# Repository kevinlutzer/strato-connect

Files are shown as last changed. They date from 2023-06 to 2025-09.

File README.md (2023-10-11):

# Strato Connect

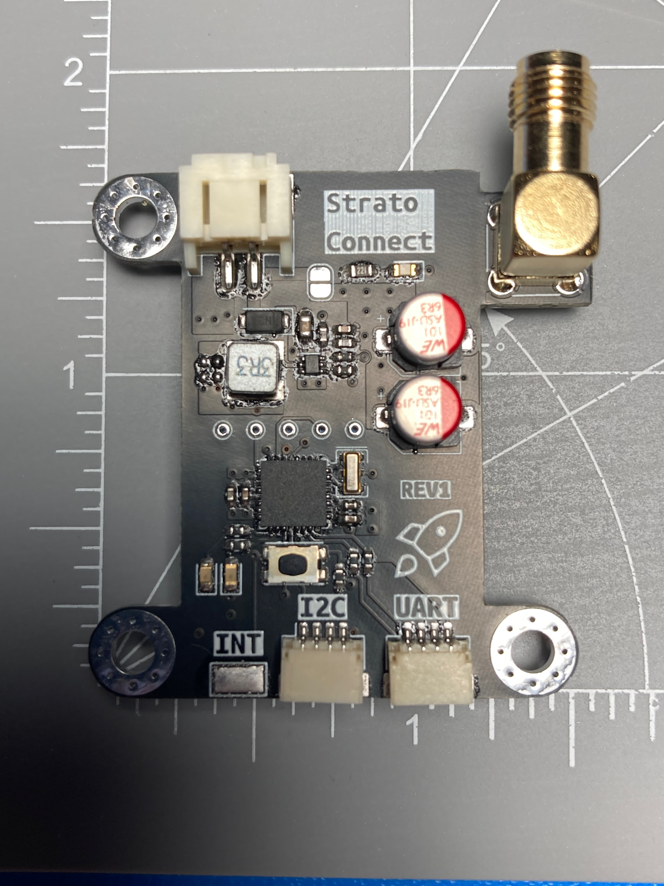
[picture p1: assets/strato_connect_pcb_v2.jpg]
Strato Connect V2 PCB Strato Connect


Strato Connect is an RF module used to send AX.25 formatted data with (G)FSK modulation over I2C. Connect a host MCU or computer to this module, and you can communicate with any AX.25 supported receiver up to 100 kilometers line of sight. 

# Rev 2.0 PCB Todo
1. The current boost regulator doesn't really work. We are getting voltage drops when there are current spikes. 
1. IRQ was not connected.
1. RX/TX labels are wrong for the uart port. 
1. Switch the JST connectors to be the 1.0mm pitch connector type used for QT/QWICC
1. Refactor the code to take an interface in for the I2C Controller instead of passing a function pointer

# Code
To compile and run tests use: `g++ test/test.cpp ax25/ax25.* test/ax25_test.h -lgtest -std=c++17 && ./a.out`
To compile code for arduino use: `arduino-cli compile -b MiniCore:avr:328 --library=./rf4463,./ax25 --output-dir=bin`

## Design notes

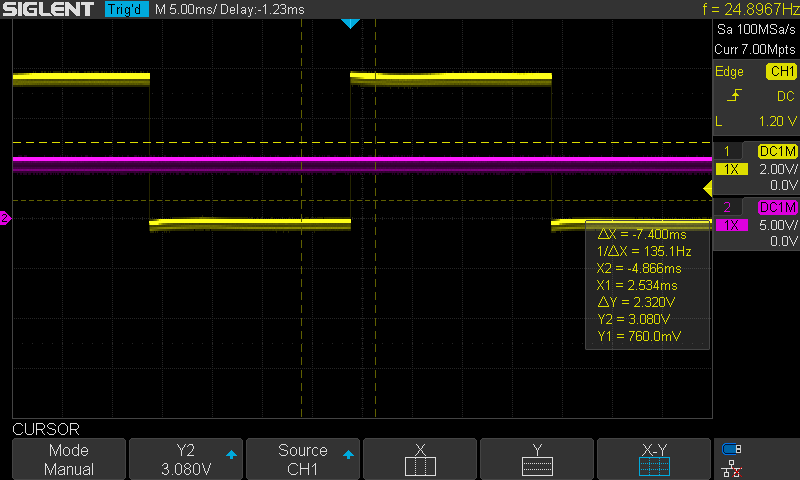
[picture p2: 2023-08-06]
documentation/SDS00004.png

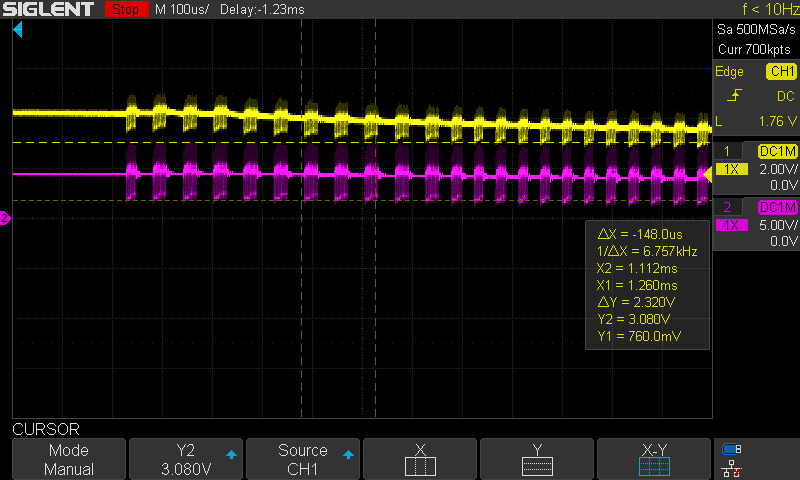
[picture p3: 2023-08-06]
documentation/SDS00003.png

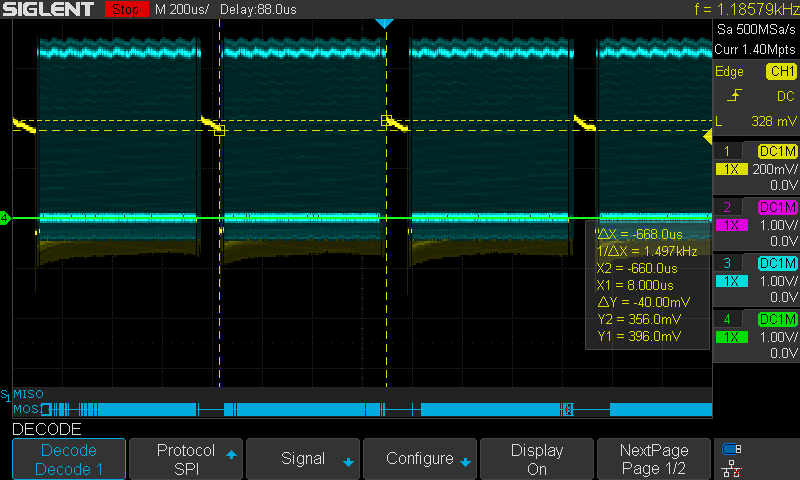
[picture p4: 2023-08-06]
documentation/SDS00001.png

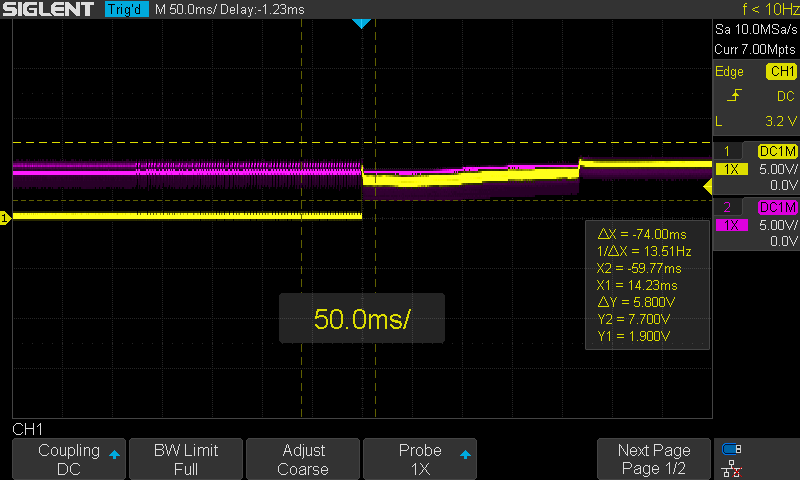
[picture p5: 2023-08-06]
documentation/SDS00005.png

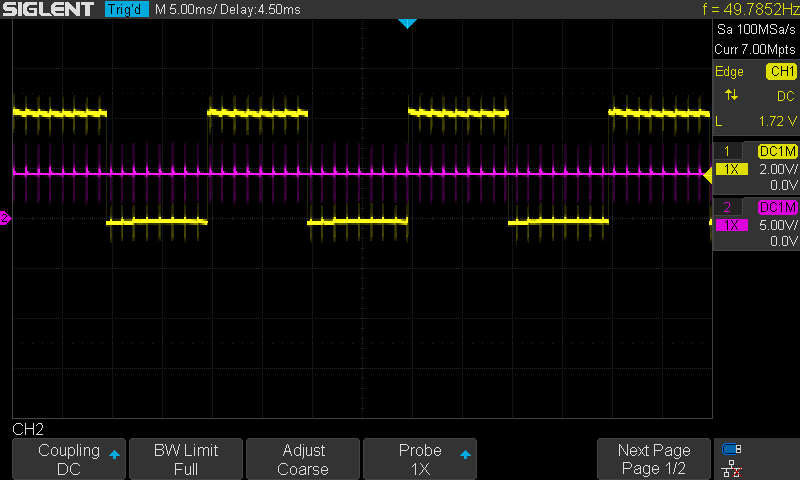
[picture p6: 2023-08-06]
documentation/SDS00002.png

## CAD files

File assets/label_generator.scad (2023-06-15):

/*
    Creates labels for the diode ring modulator pcb

    Author: Kevin Lutzer
    Date: June 13 2023
*/

// generates a rounded box with some text in the center
module generateLabel(width, height, radius, label, ts) {
    $fn=40;

    difference() {
        translate([- width / 2, - height / 2]) {
            minkowski() {
              square([width, height]);
              circle(r=radius);
            }
        }

        text(label, font="Liberation SansL:style=Bold", valign="center", halign="center", size=ts);        
    }

            
}

module generatePinHeader(width, height, radius, ts, labels, pin_pitch=2.54) {
    $fn=40;

    difference() {
        translate([- width / 2, - height / 2]) {
            minkowski() {
              square([width, height]);
              circle(r=radius);
            }
        }
        
        labels_len = len(labels);
        for (i = [0:1:len(labels)]) {
            label = labels[len(labels) - 1 - i];
            translate([-width/2, - (pin_pitch * labels_len)/2 + pin_pitch*i + pin_pitch / 2 ])
                text(label, font="Liberation Sans:style=Bold", valign="center", halign="left", size=ts);
        }
                        
    }            
}


//generatePinHeader(3.75, 4, 0.25, 1.2, ["TX", "GND", "RX"], 1.25); // UART header
//generatePinHeader(3.75, 6, 0.25, 1.2, ["GND", "VIN", "SDA", "SCL", "INT"], 1.25); // UART header
//generatePinHeader(3.75, 4, 0.25, 1.2, ["GND", "VIN"], 2.54); // Power header
//generateLabel(11.5, 1.75, 0.25, "StratoConnect", 1.2);
//generateLabel(5, 1.75, 0.25, "Rev 1", 1.2);
//generateLabel(6, 1.75, 0.25, "VIN=5V", 1.2);
//generateLabel(17.5, 1.75, 0.25, "Bypass Level Shifting", 1.2);
//generateLabel(4.5, 1.75, 0.25, "TRIG", 1.2);
//generateLabel(3.75, 1.75, 0.25, "RST", 1.2);
generatePinHeader(2.5, 4, 0.25, 1.2, ["TX", "RX"], 2.54); // Power header

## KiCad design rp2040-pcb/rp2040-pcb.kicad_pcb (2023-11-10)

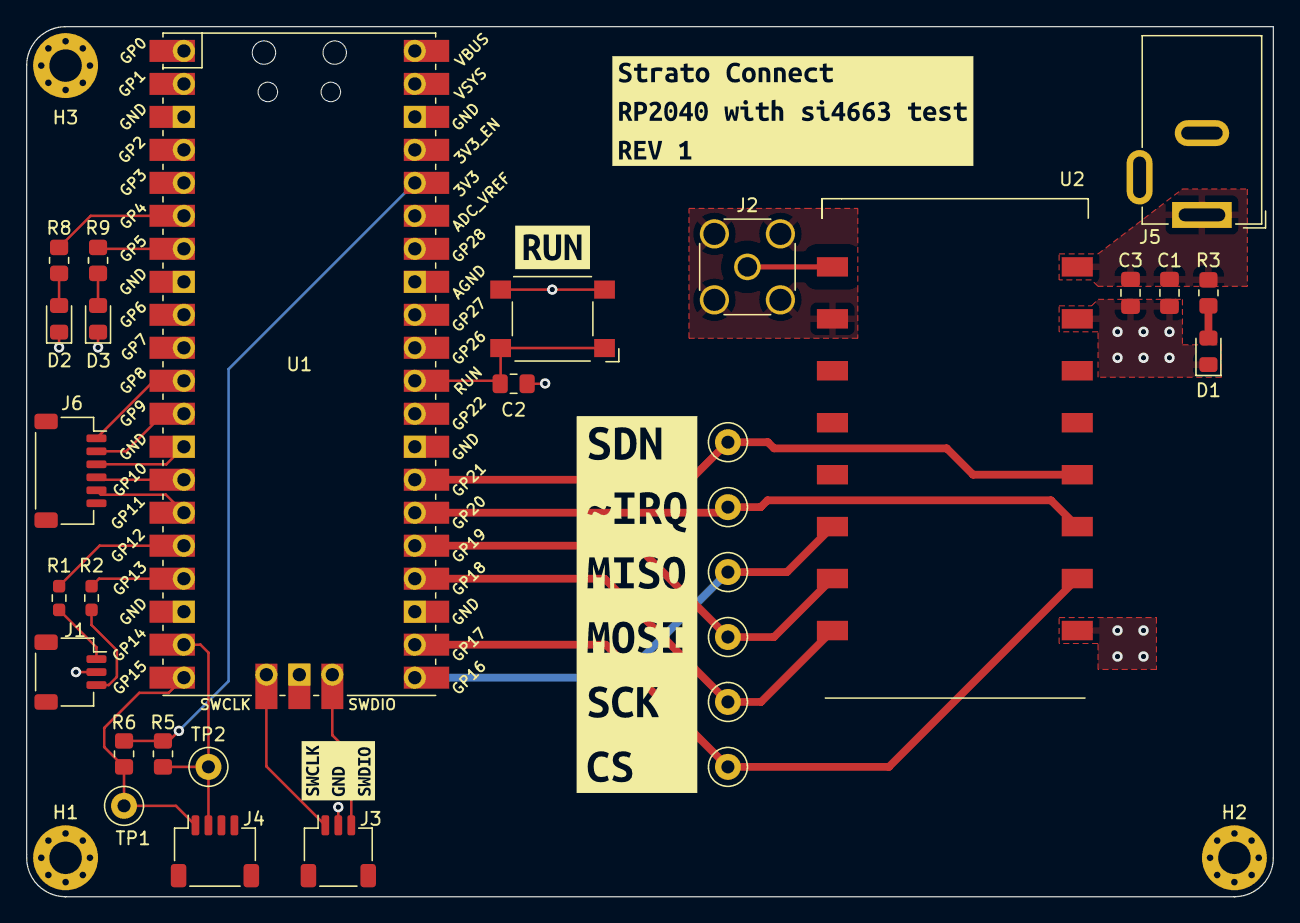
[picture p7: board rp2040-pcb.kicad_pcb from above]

Board: 2 copper layers, 96.0 x 67.0 mm, 37 parts (0 on the bottom side), 29 nets.

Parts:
C1, C2, C3: C; C_0805_2012Metric_Pad1.18x1.45mm_HandSolder
D1, D2, D3: LED; LED_0805_2012Metric_Pad1.15x1.40mm_HandSolder
H1, H2, H3: MountingHole_Pad; MountingHole_2.5mm_Pad_Via
J1, J3: Conn_01x03_Pin; JST_SH_SM03B-SRSS-TB_1x03-1MP_P1.00mm_Horizontal
J2: Conn_Coaxial; SMA_Wurth_60312002114503_Vertical
J4: Conn_01x04_Pin; JST_SH_SM04B-SRSS-TB_1x04-1MP_P1.00mm_Horizontal
J5: Barrel_Jack; BarrelJack_GCT_DCJ200-10-A_Horizontal
J6: Conn_01x06_Socket; JST_SH_SM06B-SRSS-TB_1x06-1MP_P1.00mm_Horizontal
R1, R2: 100; R_0603_1608Metric_Pad0.98x0.95mm_HandSolder
R3, R8, R9: 220; R_0805_2012Metric_Pad1.20x1.40mm_HandSolder
R5, R6: 2k2; R_0805_2012Metric_Pad1.20x1.40mm_HandSolder
SW1: SW_SPST; SW_SPST_Omron_B3FS-100xP
TP1, TP2, TP3, TP4, TP5, TP6, TP7, TP8: TestPoint; TestPoint_Loop_D1.80mm_Drill1.0mm_Beaded
U1: Pico; RPi_Pico_SMD_TH
U2: RF4463F30
kibuzzard-654DA23D: G***; kibuzzard-654DA23D
kibuzzard-654DA24D: G***; kibuzzard-654DA24D
kibuzzard-654DAC3C: G***; kibuzzard-654DAC3C
kibuzzard-654DC7E1: G***; kibuzzard-654DC7E1

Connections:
+3V3: R5.2, R6.2, U1.36 (3V3)
+VDC: C1.1, C3.1, J5.1, R3.1, U2.16 (VCC)
/RF_GND: J2.2 (Ext), U2.2 (ANT_GND)
GND: C1.2, C2.2, C3.2, D1.1 (K), D2.1 (K), D3.1 (K), H1.1, H2.1, H3.1, J1.2, J3.2, J4.4, J5.2, J6.3, SW1.2 (B), U1.3 (GND), U1.8 (GND), U1.13 (GND), U1.18 (GND), U1.23 (GND), U1.28 (GND), U1.33 (AGND), U1.38 (GND), U1.42 (GND), U2.9 (GND), U2.15 (GND)
I2C_SCL: J4.1, R6.1, TP1.1, U1.20 (GPIO15)
I2C_SDA: J4.2, R5.1, TP2.1, U1.19 (GPIO14)
LED1: R8.1, U1.6 (GPIO4)
LED2: R9.1, U1.7 (GPIO5)
unnamed: D1.2 (A), R3.2
unnamed: D2.2 (A), R8.2
unnamed: D3.2 (A), R9.2
unnamed: J1.1, R1.1
unnamed: J1.3, R2.1
unnamed: J2.1 (In), U2.1 (ANT)
RUN: C2.1, SW1.1 (A), U1.30 (RUN)
SDN: TP8.1, U1.27 (GPIO21), U2.12 (SDN)
SPI0_MISO: TP3.1, U1.21 (GPIO16), U2.6 (SDO)
SPI0_MOSI: TP4.1, U1.25 (GPIO19), U2.7 (SDI)
SPI0_SCK: TP5.1, U1.24 (GPIO18), U2.8 (SCLK)
SPI1_MISO: J6.1, U1.11 (GPIO8)
SPI1_MOSI: J6.5, U1.15 (GPIO11)
SPI1_SCK: J6.4, U1.14 (GPIO10)
SWCLK: J3.1, U1.41 (SWCLK)
SWDIO: J3.3, U1.43 (SWDIO)
UART_RX: R2.2, U1.17 (GPIO13)
UART_TX: R1.2, U1.16 (GPIO12)
~IRQ: TP7.1, U1.26 (GPIO20), U2.11 (~IRQ)
~SPI0_CS: TP6.1, U1.22 (GPIO17), U2.10 (~SEL)
~SPI1_CS: J6.2, U1.12 (GPIO9)

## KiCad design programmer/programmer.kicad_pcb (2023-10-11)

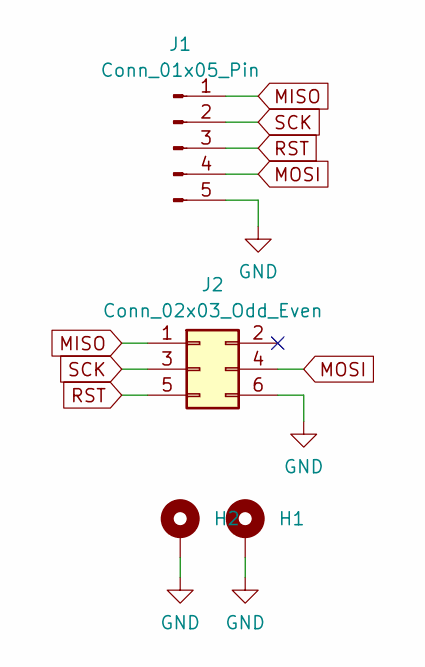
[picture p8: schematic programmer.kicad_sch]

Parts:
H1, H2: MountingHole_Pad; MountingHole_3mm_Pad_Via
J1: Conn_01x05_Pin; PinHeader_1x05_P2.54mm_Vertical
J2: Conn_02x03_Odd_Even; PinHeader_2x03_P2.54mm_Vertical

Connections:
GND: H1.1, H2.1, J1.5, J2.6
MISO: J1.1, J2.1
MOSI: J1.4, J2.4
RST: J1.3, J2.5
SCK: J1.2, J2.3

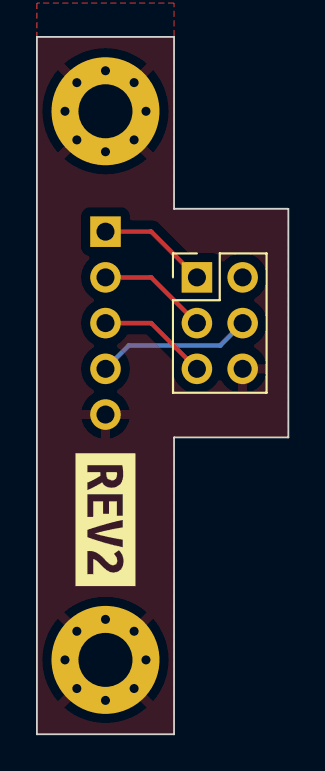
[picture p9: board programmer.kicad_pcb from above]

Board: 2 copper layers, 14.0 x 38.7 mm, 5 parts (1 on the bottom side), 5 nets.

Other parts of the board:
kibuzzard-64ED132C: G***; kibuzzard-64ED132C

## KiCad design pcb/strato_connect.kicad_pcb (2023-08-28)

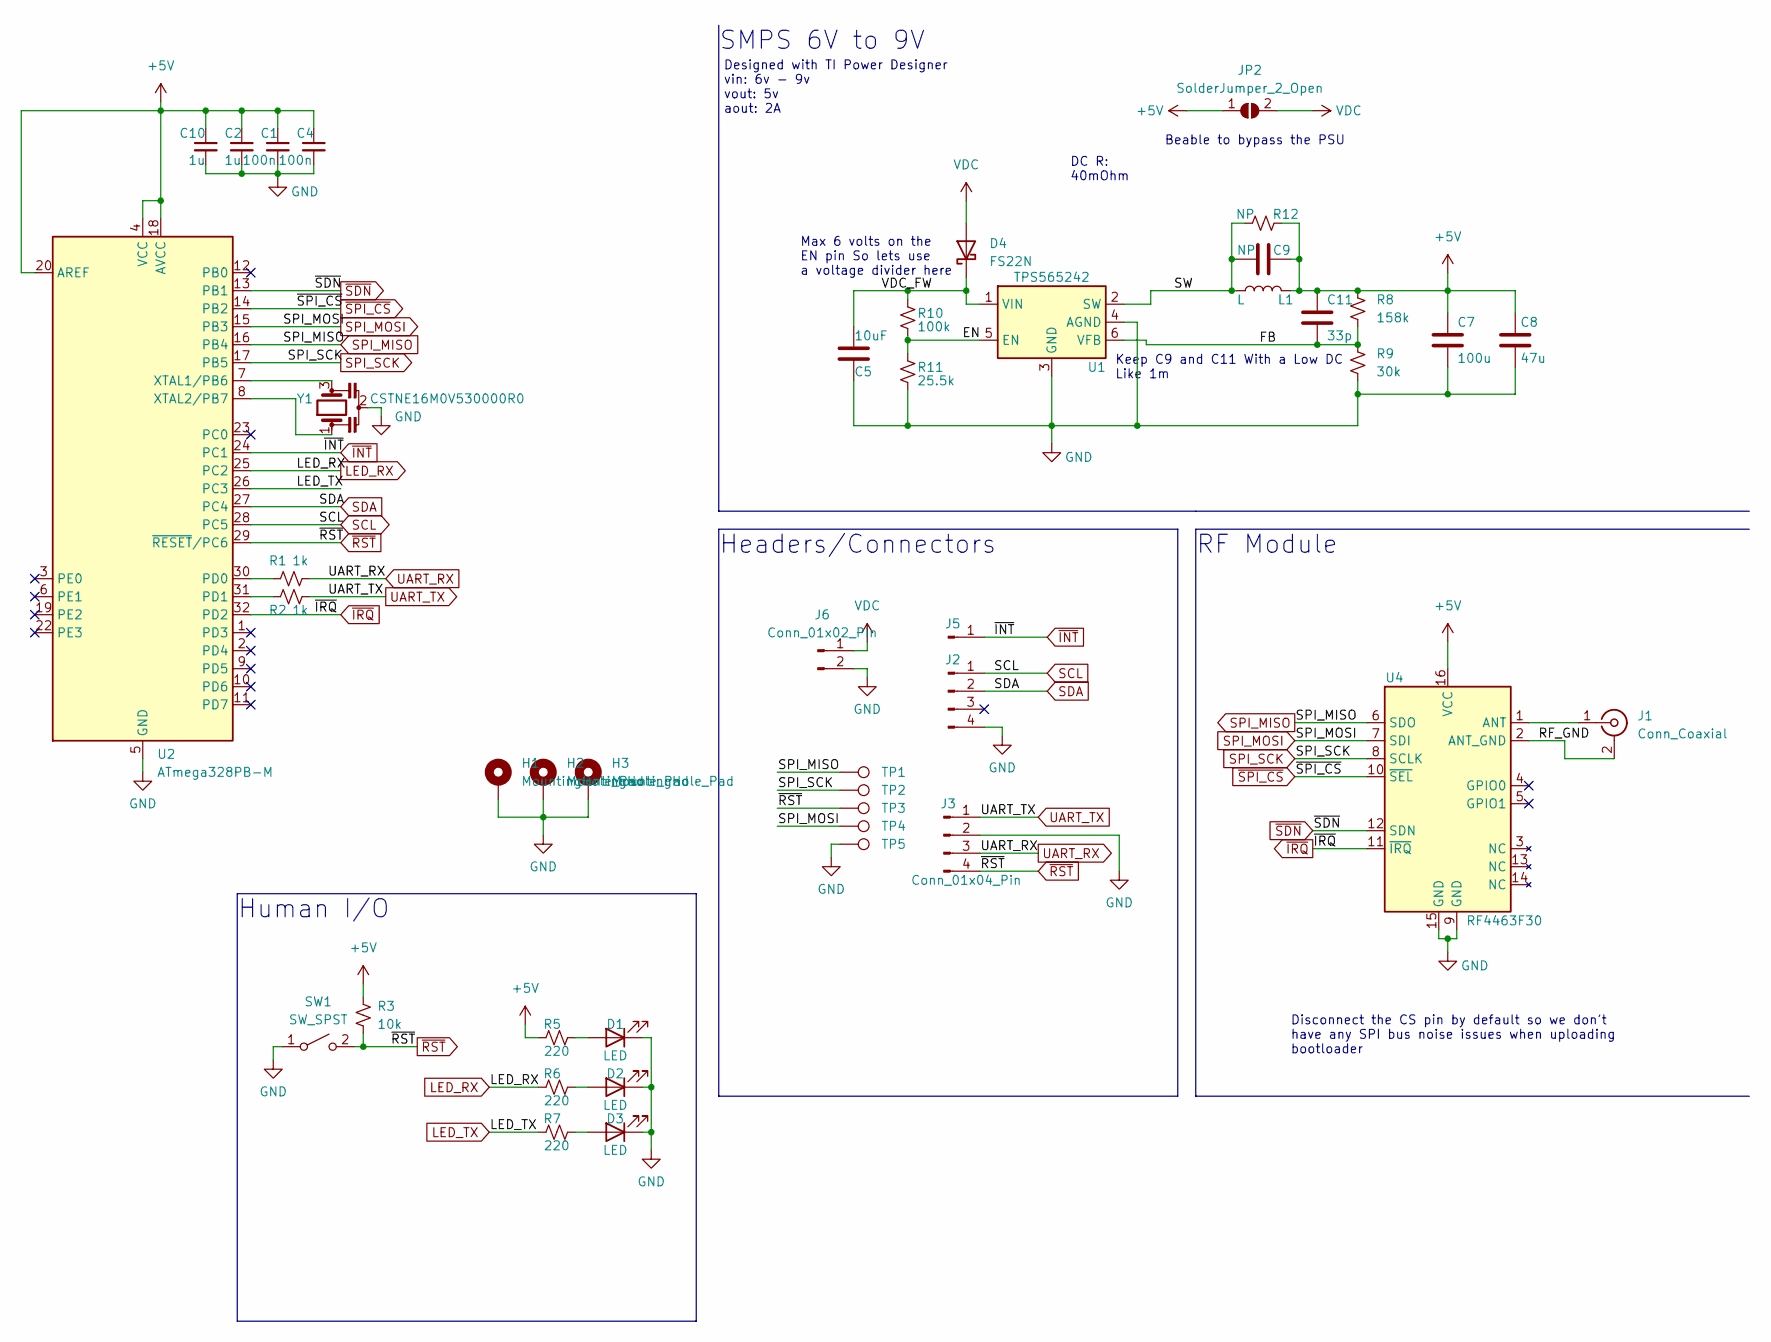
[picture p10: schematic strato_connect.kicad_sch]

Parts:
C1, C4: 100n; C_0402_1005Metric_Pad0.74x0.62mm_HandSolder
C2, C10: 1u; C_0402_1005Metric_Pad0.74x0.62mm_HandSolder
C5: 10uF; C_0603_1608Metric_Pad1.08x0.95mm_HandSolder
C7: 100u; CP_Elec_5x5.3
C8: 47u; CP_Elec_5x5.3
C9: NP; C_0402_1005Metric_Pad0.74x0.62mm_HandSolder
C11: 33p; C_0402_1005Metric_Pad0.74x0.62mm_HandSolder
D1, D2, D3: LED; LED_0603_1608Metric
D4: FS22N; D_SOD-123F
H1, H2, H3: MountingHole_Pad; MountingHole_3.2mm_M3_Pad_Via
J1: Conn_Coaxial; SMA_Wurth_60312002114503_Vertical
J2, J3: Conn_01x04_Pin; JST_SH_SM04B-SRSS-TB_1x04-1MP_P1.00mm_Horizontal
J5: Conn_01x01_Pin; TestPoint_Keystone_5019_Minature
J6: Conn_01x02_Pin; JST_PH_S2B-PH-SM4-TB_1x02-1MP_P2.00mm_Horizontal
JP2: SolderJumper_2_Open; SolderJumper-2_P1.3mm_Open_RoundedPad1.0x1.5mm
L1: L; L_Wurth_WE-LQSH-4025
R1, R2: 1k; R_0402_1005Metric_Pad0.72x0.64mm_HandSolder
R3: 10k; R_0402_1005Metric_Pad0.72x0.64mm_HandSolder
R5: 220; R_0603_1608Metric_Pad0.98x0.95mm_HandSolder
R6, R7: 220; R_0402_1005Metric_Pad0.72x0.64mm_HandSolder
R8: 158k; R_0402_1005Metric_Pad0.72x0.64mm_HandSolder
R9: 30k; R_0402_1005Metric_Pad0.72x0.64mm_HandSolder
R10: 100k; R_0402_1005Metric_Pad0.72x0.64mm_HandSolder
R11: 25.5k; R_0402_1005Metric_Pad0.72x0.64mm_HandSolder
R12: NP; R_0402_1005Metric_Pad0.72x0.64mm_HandSolder
SW1: SW_SPST; SW_Push_1P1T_NO_CK_KMR2
TP1, TP2, TP3, TP4, TP5: TestPoint; TestPoint_THTPad_D1.0mm_Drill0.5mm
U1: TPS565242; SOT-563
U2: ATmega328PB-M; QFN-32-1EP_5x5mm_P0.5mm_EP3.1x3.1mm
U4: RF4463F30
Y1: CSTNE16M0V530000R0; Resonator_SMD_Murata_CSTxExxV-3Pin_3.0x1.1mm

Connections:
+5V: C1.1, C2.1, C4.1, C7.1, C8.1, C9.1, C10.1, C11.1, JP2.1 (A), L1.2, R3.1, R5.1, R8.1, R12.2, U2.4 (VCC), U2.18 (AVCC), U2.20 (AREF), U4.16 (VCC)
/EN: R10.2, R11.1, U1.5 (EN)
/FB: C11.2, R8.2, R9.1, U1.6 (VFB)
/RF_GND: J1.2 (Ext), U4.2 (ANT_GND)
/SW: C9.2, L1.1, R12.1, U1.2 (SW)
/VDC_FW: C5.1, D4.1 (K), R10.1, U1.1 (VIN)
GND: C1.2, C2.2, C4.2, C5.2, C7.2, C8.2, C10.2, D1.1 (K), D2.1 (K), D3.1 (K), H1.1, H2.1, H3.1, J2.4, J3.2, J6.2, R9.2, R11.2, SW1.1 (A), TP5.1, U1.3 (GND), U1.4 (AGND), U2.5 (GND), U2.21 (GND), U2.33 (GND), U4.9 (GND), U4.15 (GND), Y1.2
LED_RX: R6.1, U2.25 (PC2)
LED_TX: R7.1, U2.26 (PC3)
unnamed: D1.2 (A), R5.2
unnamed: D2.2 (A), R6.2
unnamed: D3.2 (A), R7.2
unnamed: J1.1 (In), U4.1 (ANT)
unnamed: R1.1, U2.30 (PD0)
unnamed: R2.1, U2.31 (PD1)
unnamed: U2.7 (XTAL1/PB6), Y1.3
unnamed: U2.8 (XTAL2/PB7), Y1.1
SCL: J2.1, U2.28 (PC5)
SDA: J2.2, U2.27 (PC4)
SPI_MISO: TP1.1, U2.16 (PB4), U4.6 (SDO)
SPI_MOSI: TP4.1, U2.15 (PB3), U4.7 (SDI)
SPI_SCK: TP2.1, U2.17 (PB5), U4.8 (SCLK)
UART_RX: J3.3, R1.2
UART_TX: J3.1, R2.2
VDC: D4.2 (A), J6.1, JP2.2 (B)
~INT: J5.1, U2.24 (PC1)
~IRQ: U2.32 (PD2), U4.11 (~IRQ)
~RST: J3.4, R3.2, SW1.2 (B), TP3.1, U2.29 (~RESET/PC6)
~SDN: U2.13 (PB1), U4.12 (SDN)
~SPI_CS: U2.14 (PB2), U4.10 (~SEL)

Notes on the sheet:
Headers/Connectors
Human I/O
DC R: 40mOhm
SMPS 6V to 9V
Max 6 volts on the EN pin So lets use a voltage divider here
Keep C9 and C11 With a Low DC Like 1m
Designed with TI Power Designer vin: 6v - 9v vout: 5v aout: 2A
RF Module
Disconnect the CS pin by default so we don't have any SPI bus noise issues when uploading bootloader
Beable to bypass the PSU

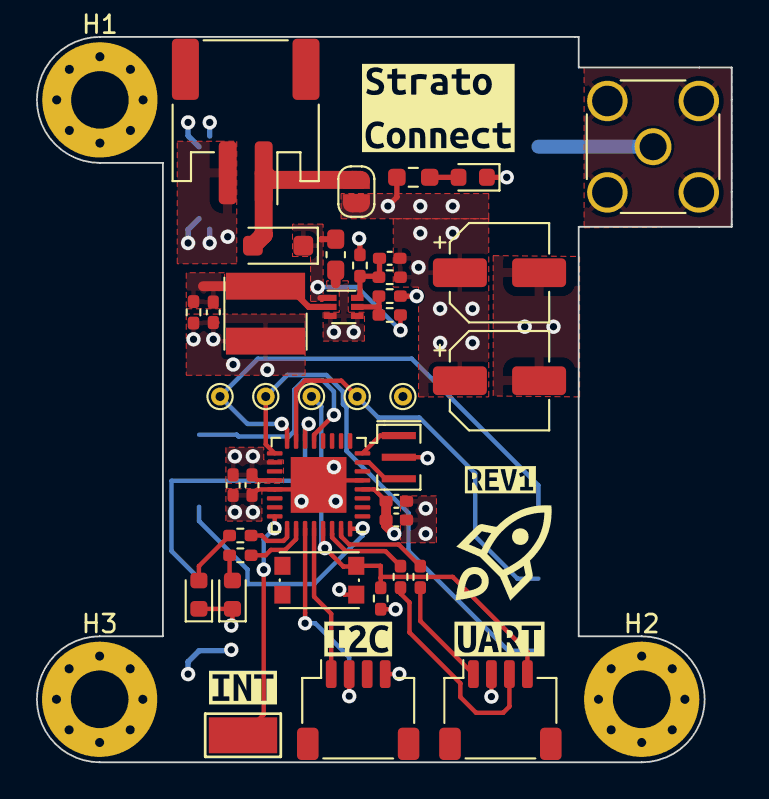
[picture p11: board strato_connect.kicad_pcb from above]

Board: 4 copper layers, 38.6 x 40.3 mm, 49 parts (1 on the bottom side), 30 nets.

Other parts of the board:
kibuzzard-64B1A87B: G***; kibuzzard-64B1A87B
kibuzzard-64B1A828: G***; kibuzzard-64B1A828
kibuzzard-64B1A895: G***; kibuzzard-64B1A895
kibuzzard-64B1B5E1: G***; kibuzzard-64B1B5E1
kibuzzard-64B1B6FD: G***; kibuzzard-64B1B6FD

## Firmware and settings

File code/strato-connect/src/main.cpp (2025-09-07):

#include "rf4463.hpp"
#include <SPI.h>
// #include "ax25.hpp"
// #include "i2ccontroller.hpp"
// #include <SPI.h>
// #include <Wire.h>
// #include <Adafruit_BME280.h>

#define IRQ 2
#define SDN 9
#define SEL 10
#define SCL 19

#define LED_RX 16
#define LED_TX 17
#define INT 15

// Raspberry Pi pico RP2040 pinout
#define SCK 10
#define MISO 11
#define MOSI 12
#define CS 13

SPIClass &spiClass = SPI1; 
RF4463 rf4463(IRQ, SDN, SEL);
unsigned char tx_buf[] = { "NEW HELLO WORLD!!!" };
unsigned char val;
unsigned char flag = 0;  //  flag of rx mode
unsigned char rx_len;
unsigned char rx_buf[20];

void setup() {
  Serial.begin(9600);

  pinMode(LED_RX, OUTPUT);
  pinMode(LED_TX, OUTPUT);
  pinMode(INT, OUTPUT);

  digitalWrite(LED_RX, HIGH);

  digitalWrite(INT, HIGH);

  if (!rf4463.init())
    Serial.println("Init fail!");
  else
    Serial.println("Init success!");

  if (!rf4463.setTxPower(127))
    Serial.println("Failed to set power to max!");
}

void loop() {
  digitalWrite(LED_TX, LOW);
  delay(1000);
  digitalWrite(LED_TX, HIGH);
  rf4463.txPacket(tx_buf, sizeof(tx_buf));
  delay(1000);
}

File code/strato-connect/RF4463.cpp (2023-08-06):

#include "RF4463.h"
#include <SPI.h>
// Generated with wireless development suite by silicon labs
#include "radio_config_Si4463.h"

// #define DEBUG_RF4463

// Configuration parameters from "radio_config_Si4463.h"
const uint8_t RF4463_CONFIGURATION_DATA[] = RADIO_CONFIGURATION_DATA_ARRAY;

RF4463::RF4463(uint8_t nIRQPin, uint8_t sdnPin,uint8_t nSELPin)
{
	_nIRQPin = nIRQPin;
	_sdnPin = sdnPin;
	_nSELPin = nSELPin;
}
void RF4463::spiInit()
{
	SPI.begin();
	//init slave select pin
	pinMode(_nSELPin, OUTPUT);
	digitalWrite(_nSELPin, HIGH);

	// depends on RF4463 spi timing
	SPI.setBitOrder(MSBFIRST);
  
	// too fast may cause error
	SPI.setClockDivider(SPI_CLOCK_DIV16);
	SPI.setDataMode(SPI_MODE0);
}
void RF4463::pinInit()
{
	pinMode(_sdnPin, OUTPUT);
	digitalWrite(_sdnPin, HIGH);
	pinMode(_nIRQPin, INPUT);
}
bool RF4463::init()
{
	pinInit();
	spiInit();

	uint8_t buf[20];

	// reset RF4463
	powerOnReset();


  	// check if RF4463 works
	if(!checkDevice())
	{
		return false;
	}


	// Set RF parameter,like frequency,data rate etc
	setConfig(RF4463_CONFIGURATION_DATA,sizeof(RF4463_CONFIGURATION_DATA));
	
	// set antenna switch,in RF4463 is GPIO2 and GPIO3
	// don't change setting of GPIO2,GPIO3,NIRQ,SDO
	buf[0]  = RF4463_GPIO_NO_CHANGE; 
	buf[1]  = RF4463_GPIO_NO_CHANGE;
	buf[2]  = RF4463_GPIO_RX_STATE;
	buf[3]  = RF4463_GPIO_TX_STATE;
	buf[4]  = RF4463_NIRQ_INTERRUPT_SIGNAL; 
	buf[5]  = RF4463_GPIO_SPI_DATA_OUT; 
	setCommand(6,RF4463_CMD_GPIO_PIN_CFG,buf);
	
	// frequency adjust
	// frequency will inaccurate if change this parameter
	buf[0]  = 98;
	setProperties(RF4463_PROPERTY_GLOBAL_XO_TUNE,1,buf);

	// tx = rx = 64 byte,PH mode ,high performance mode
	buf[0] = 0x40;
	setProperties(RF4463_PROPERTY_GLOBAL_CONFIG,1,buf);

	// set preamble
	buf[0]  = 0x08;		//  8 bytes Preamble			
	buf[1]  = 0x14;		//  detect 20 bits
	buf[2]  = 0x00;						
	buf[3]  = 0x0f;
	buf[4]  = RF4463_PREAMBLE_FIRST_1|RF4463_PREAMBLE_LENGTH_BYTES|RF4463_PREAMBLE_STANDARD_1010;
	buf[5]  = 0x00;
	buf[6]  = 0x00;
	buf[7]  = 0x00;
	buf[8]  = 0x00;
	setProperties(RF4463_PROPERTY_PREAMBLE_TX_LENGTH,9,buf);

	// set sync words
	buf[0] = 0x2d;
	buf[1] = 0xd4;
	setSyncWords(buf,2);
   
    // set CRC
	buf[0] = RF4463_CRC_SEED_ALL_1S|RF4463_CRC_ITU_T ;			
	setProperties(RF4463_PROPERTY_PKT_CRC_CONFIG,1,buf);
	
	buf[0]=RF4463_CRC_ENDIAN;
	setProperties(RF4463_PROPERTY_PKT_CONFIG1,1,buf);

	buf[0]=RF4463_IN_FIFO|RF4463_DST_FIELD_ENUM_2;
	buf[1]=RF4463_SRC_FIELD_ENUM_1;
	buf[2]=0x00;
	setProperties(RF4463_PROPERTY_PKT_LEN,3,buf);
	
	// set length of Field 1 -- 4
	// variable len,field as length field,field 2 as data field
	// didn't use field 3 -- 4
	buf[0] = 0x00;
	buf[1] = 0x01;
	buf[2] = RF4463_FIELD_CONFIG_PN_START;
	buf[3] = RF4463_FIELD_CONFIG_CRC_START|RF4463_FIELD_CONFIG_SEND_CRC|RF4463_FIELD_CONFIG_CHECK_CRC|RF4463_FIELD_CONFIG_CRC_ENABLE;
	buf[4] = 0x00;
	buf[5] = 50;
	buf[6] = RF4463_FIELD_CONFIG_PN_START;
	buf[7] = RF4463_FIELD_CONFIG_CRC_START|RF4463_FIELD_CONFIG_SEND_CRC|RF4463_FIELD_CONFIG_CHECK_CRC|RF4463_FIELD_CONFIG_CRC_ENABLE;;
	buf[8]  = 0x00; 
	buf[9] = 0x00;
	buf[10] = 0x00;
	buf[11] = 0x00;
	setProperties(RF4463_PROPERTY_PKT_FIELD_1_LENGTH_12_8 ,12,buf);
  
	buf[0] = 0x00;
	buf[1] = 0x00;
	buf[2] = 0x00;
	buf[3] = 0x00;
	buf[4] = 0x00;
	buf[5] = 0x00;
	buf[6] = 0x00;
	buf[7] = 0x00;
	setProperties(RF4463_PROPERTY_PKT_FIELD_4_LENGTH_12_8,8,buf);

	// set max tx power
  setTxPower(127);

  return true;
}
void RF4463::powerOnReset()
{
    uint8_t buf[]={RF_POWER_UP};

    digitalWrite(_sdnPin, HIGH); 
    delay(100);
    digitalWrite(_sdnPin, LOW);
    delay(20);						// wait for RF4463 stable

	// send power up command
	digitalWrite(_nSELPin, LOW);
	spiWriteBuf(sizeof(buf),buf);
	digitalWrite(_nSELPin, HIGH);   
	
	delay(200);
}
void RF4463::setConfig(const uint8_t* parameters,uint16_t paraLen)
{
	// command buf starts with length of command in RADIO_CONFIGURATION_DATA_ARRAY
	uint8_t cmdLen;
	uint8_t command;
	uint16_t pos;
	uint8_t buf[30];

	// power up command had already send
	paraLen=paraLen-1;
	cmdLen=parameters[0];
	pos=cmdLen+1;
	
	while(pos<paraLen)
	{
		cmdLen=parameters[pos++]-1;		// get command lend
		command=parameters[pos++];		// get command
		memcpy(buf,parameters+pos,cmdLen);		// get parameters
		
		setCommand(cmdLen,command,buf);
		pos=pos+cmdLen;
	}
}
bool RF4463::checkDevice()
{
	uint8_t buf[9];
	uint16_t partInfo;
	getCommand(9,RF4463_CMD_PART_INFO,buf);		// read part info to check if 4463 works
		
	partInfo=buf[2]<<8|buf[3];

	if(partInfo != 0x4463){
		return false;
	}

  return true;
}
bool RF4463::txPacket(uint8_t* sendbuf,uint8_t sendLen)
{
	uint16_t txTimer;

	fifoReset();		 				// clr fifo
	writeTxFifo(sendbuf,sendLen);		// load data to fifo	
	setTxInterrupt();
	clrInterrupts();					// clr int factor	
	enterTxMode();						// enter TX mode
	
	txTimer=RF4463_TX_TIMEOUT;
	while(txTimer--)
	{
		if(waitnIRQ())					// wait INT
		{
			return true;
		}
		delay(1);
	}
	init();								// reset RF4463 if tx time out

	return false;
}
uint8_t RF4463::rxPacket(uint8_t* recvbuf)
{
	uint8_t rxLen;
	rxLen=ReadRxFifo(recvbuf);			// read data from fifo
	fifoReset();						// clr fifo

	return rxLen;
}

bool RF4463::rxInit()
{		
	uint8_t length;
	length=50;
	setProperties(RF4463_PROPERTY_PKT_FIELD_2_LENGTH_7_0, sizeof(length),&length);	// reload rx fifo size
	fifoReset();				// clr fifo
	setRxInterrupt();
	clrInterrupts();			// clr int factor	
	enterRxMode();				// enter RX mode
	return true;
}
bool RF4463::waitnIRQ()
{
	return !digitalRead(_nIRQPin);		// inquire interrupt
}
void RF4463::enterTxMode()
{
	uint8_t buf[]={0x00,0x30,0x00,0x00};
	buf[0]=RF4463_FREQ_CHANNEL;
	setCommand(4,RF4463_CMD_START_TX ,buf);
}
void RF4463::enterRxMode()
{
	uint8_t buf[]={0x00,0x00,0x00,0x00,0x00,0x08,0x08};
	buf[0]=RF4463_FREQ_CHANNEL;
	setCommand(7,RF4463_CMD_START_RX ,buf);
}

int8_t RF4463::getRSSI(){
  uint8_t buf_len = 6;
  uint8_t buf[buf_len];

  getCommand(6, RF4463_CMD_GET_MODEM_STATUS, buf);		// read part info to check if 4463 works
  return buf[3];
  uint8_t half_buf = buf[3] / 2;
  int8_t rssi = half_buf - RF4463_RSSI_CAL_CONSTANT;
  return rssi;
}
bool RF4463::enterStandbyMode()
{
	uint8_t data=0x01;
	return setCommand(1,RF4463_CMD_CHANGE_STATE,&data);
}
bool RF4463::setTxInterrupt()
{
	uint8_t buf[3]={0x01,0x20,0x00};			// enable PACKET_SENT interrupt
	return setProperties(RF4463_PROPERTY_INT_CTL_ENABLE, 3,buf);
}
bool RF4463::setRxInterrupt()
{
	uint8_t buf[3]={0x03,0x18,0x00};			// enable PACKET_RX interrupt
	return setProperties(RF4463_PROPERTY_INT_CTL_ENABLE, 3,buf);
}
bool RF4463::clrInterrupts()
{
    uint8_t buf[] = { 0x00, 0x00, 0x00 };  
    return setCommand(sizeof(buf),RF4463_CMD_GET_INT_STATUS,buf);
}
void RF4463::writeTxFifo(uint8_t* databuf,uint8_t length)
{
	setProperties(RF4463_PROPERTY_PKT_FIELD_2_LENGTH_7_0, sizeof(length),&length);
	uint8_t buf[length+1];
	buf[0]=length;
	memcpy(buf+1,databuf,length);
	setCommand(length+1,RF4463_CMD_TX_FIFO_WRITE,buf);
}
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

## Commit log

2023-05-25 add base pcb with crystal, reset switch and bypassing caps
    [stratoconnect.kicad_pcb, stratoconnect.kicad_sch]
2023-05-26 draw out the base schematic with the RF module
    [stratoconnect.kicad_sch]
2023-05-31 add rough margin
    [stratoconnect.kicad_pcb, stratoconnect.kicad_sch]
2023-06-10 finish the shcematic, need to adjust component packages for headers, inductors and some of the resistors
    [stratoconnect.kicad_sch]
2023-06-10 add some more annotations to the smps
    [stratoconnect.kicad_sch]
2023-06-10 add 6060 Inductor foodprint
    [stratoconnect.kicad_pcb, stratoconnect.kicad_sch]
2023-06-10 build out the VQFN7-7 footbring for the boost converter
    [stratoconnect.kicad_pcb, stratoconnect.kicad_sch]
2023-06-11 update schematic to add mroe room for the smps
    [stratoconnect.kicad_pcb, stratoconnect.kicad_sch]
2023-06-12 finish routing the smps, need to extend the footprint pads for the rf module
    [stratoconnect.kicad_pcb, stratoconnect.kicad_sch]
2023-06-13 add some of the header labels we need. Finish routing everything but uart, the iscp header, and some other small stuff
    [label_generator.scad, stratoconnect.kicad_pcb, stratoconnect.kicad_sch]
2023-06-15 finish the design
    [label_generator.scad, stratoconnect.kicad_pcb, stratoconnect.kicad_sch]
2023-06-15 add gerbers
    [stratoconnect-B_Cu.gbl, stratoconnect-B_Mask.gbs, stratoconnect-B_Paste.gbp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]
2023-06-19 add bom, readjust capactor annotations
    [stratoconnect.kicad_pcb, stratoconnect.kicad_sch]
2023-06-28 add notes about the v2 version of the pcb
    [stratoconnect.kicad_pcb]
2023-07-02 add labels update rf lib
    [stratoconnect.kicad_pcb, stratoconnect.kicad_sch]
2023-07-03 remove the i2c level shifter, add the TPS565 smps chip
    [stratoconnect.kicad_sch]
2023-07-03 fix all the erc warnings
    [stratoconnect.kicad_sch]
2023-07-07 rename the schematic
    [stratoconnect.kicad_pcb, stratoconnect.kicad_sch]
2023-07-07 rough layout of the rev2 pcb
    [strato_connect.kicad_pcb, strato_connect.kicad_sch]
2023-07-13 get most of the layout done, need to add some sort of icsp header pins
    [strato_connect.kicad_pcb, strato_connect.kicad_sch]
2023-07-14 pass DRC with the schematic capture
    [strato_connect.kicad_pcb, strato_connect.kicad_sch]
2023-07-14 add the 4025 Weurth inductor footprint in
    [strato_connect.kicad_pcb, strato_connect.kicad_sch]
2023-07-14 pass drc rules for files, just have to add the silk screen
    [strato_connect.kicad_pcb, strato_connect.kicad_sch]
2023-07-14 Switch the coax connector type
    [strato_connect.kicad_pcb, strato_connect.kicad_sch]
2023-08-01 add v2 files for the pcb, add the base code directory
    [programmer-B_Cu.gbl, programmer-B_Cu.gbr, programmer-B_Mask.gbr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]
2023-08-23 use a fixed frame init
2023-08-25 add the base i2c controller with a ping handler
2023-08-26 i2c controller constructor talking two wire instance
2023-08-28 update programming pcb so it can be secured to the stemma grid
    [programmer.kicad_pcb, strato_connect.kicad_pcb]
2023-10-11 update documentation
    [programmer-B_Cu.gbl, programmer-B_Mask.gbs, programmer-B_Paste.gbp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]
2023-11-10 add the rp2040/si4663 test pcb
    [rp2040-pcb.kicad_pcb, rp2040-pcb.kicad_sch]
